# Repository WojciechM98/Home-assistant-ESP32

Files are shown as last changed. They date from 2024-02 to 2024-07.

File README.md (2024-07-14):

# Home-assistant-ESP32
Home assistand board using ESP32 controlled with MQTT protocol.

## Main purpose of Home assistant board
The project was created with the thought of controlling LED strips with MQTT protocol via phone app. A moment later, the idea of controlling and connecting many devices appeared such as water pump for watering plants plants, temperature sensors, lamps and so on.
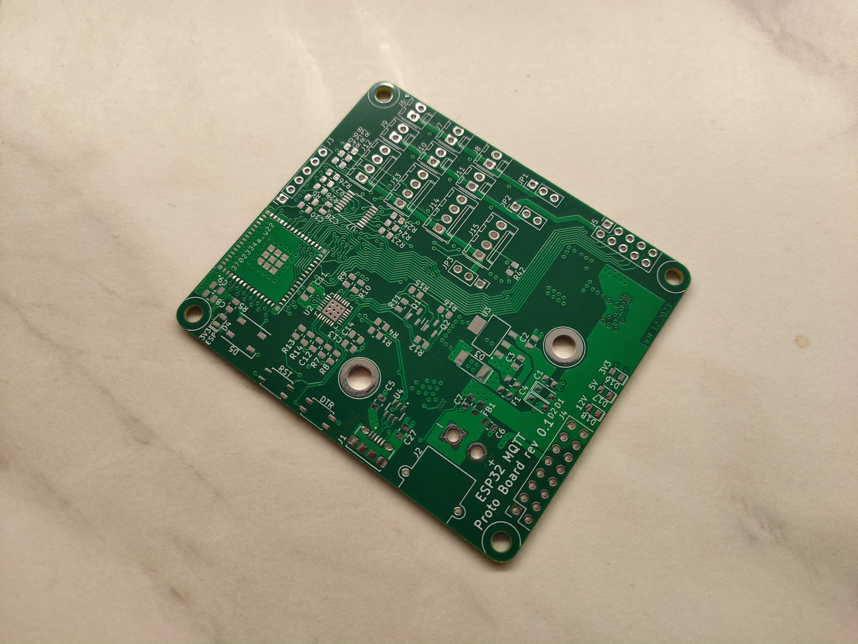
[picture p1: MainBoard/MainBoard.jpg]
Main board prototype version 0.2.


Prototype mainboard version 0.1 consist of:
- Espressif ESP32 S2 mini 1 chip,
- CP2102N series USB to UART bridge controller,
- XT30PW-M connector for powering board with up to 15V DC external power source,
- Onboard 3.3V and 5V buck converters capable of 3A current load each,
- 4 I/O molex KK254 4 pin connectors,
- 8 output molex KK254 2 pin connectors,
- 2 connectors for additional expansion of the mainboard,
- UART pin header for externel programmer connection.

### I/O connectors
Each connector consists of ground and voltage pins (jumper selection 3.3V or 5V), output signal and input signal with ESD protection schottky diodes.

### Output connectors
Output connector consists of voltage pin (jumper selection 3.3V, 5V or external power from XT30PW-M connector) and n-mosfet switching to ground. Those headers are capable of PWM control. Used DMN3023L mosfets are capable of 30V and up to 6.3A continous drain current. There is also super fast recovery DFLU1200-7 diode protecting device from reverse current flow.

### Additional expansion connectors
Those connectors uses the rest of gpio ESP pins and also provide SPI and I2C protocols.

## ACControl board
This board allows to control AC powered devices.
Control signals are seperated from AC side with SFH6156-1T optotransistors for safety purpose. AZ921-1A-12DE relays are used for switching AC current.
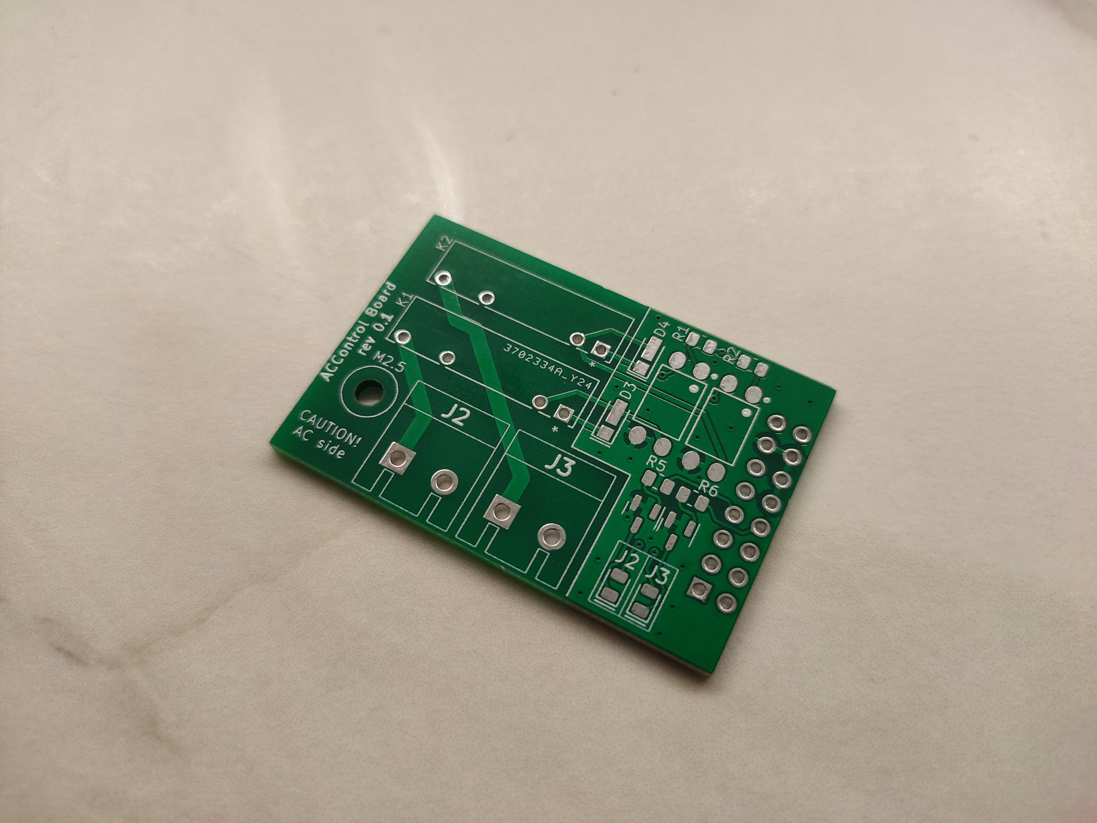
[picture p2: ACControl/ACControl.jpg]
ACControl prototype version 0.1.


## TempSensRTC
Addidtional board for temperature measurement. Can be used with MAX31865 chip for resisatance temperature detectors (RTDs) or with MAX31855 chip that allows to use theremocouples like K-type thermocouple. 
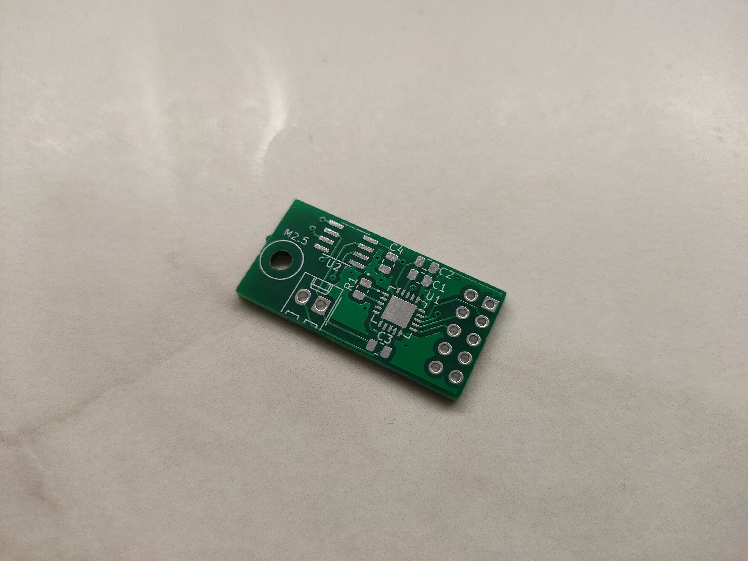
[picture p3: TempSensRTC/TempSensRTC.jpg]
TempSensRTC prototype version 0.1.


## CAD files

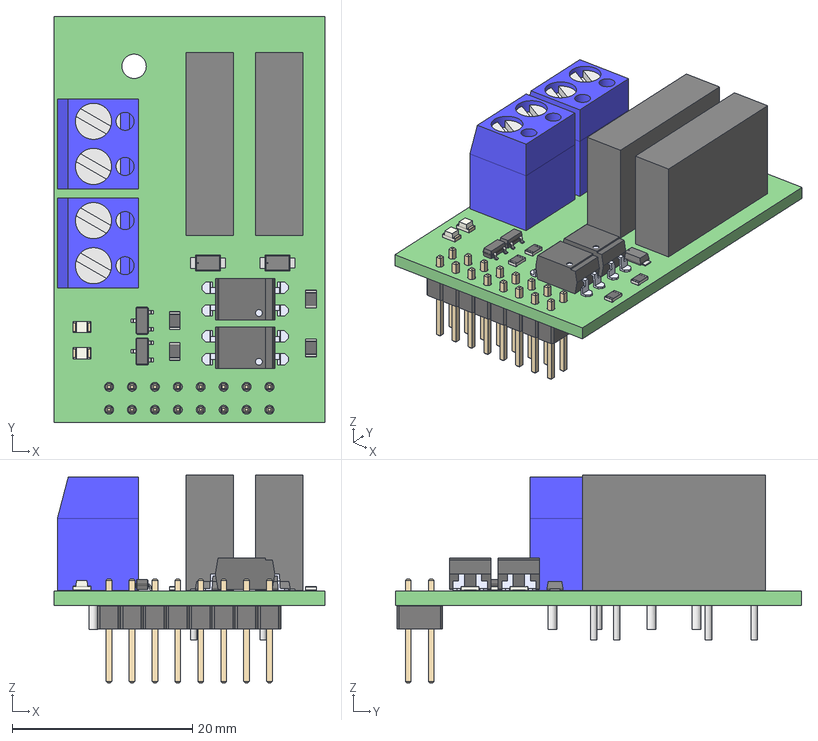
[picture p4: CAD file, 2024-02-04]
ACControl/control.step
30.0 x 45.0 x 23.0 mm
ACControl PCB

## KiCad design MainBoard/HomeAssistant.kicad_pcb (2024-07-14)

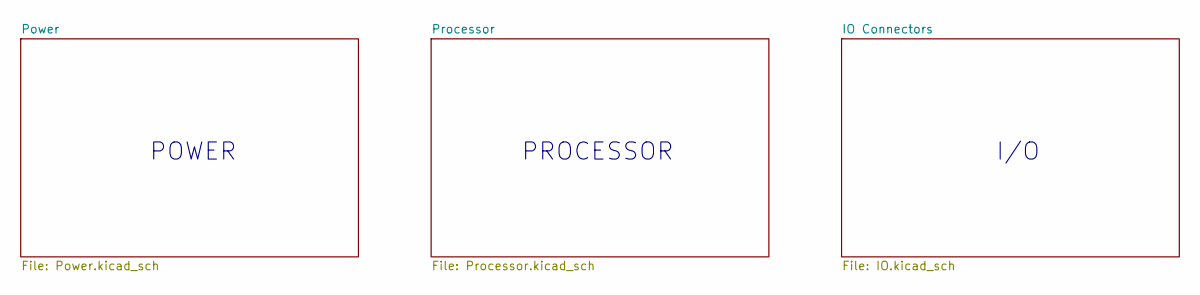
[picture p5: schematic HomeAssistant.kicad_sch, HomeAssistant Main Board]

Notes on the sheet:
I/O
POWER
PROCESSOR

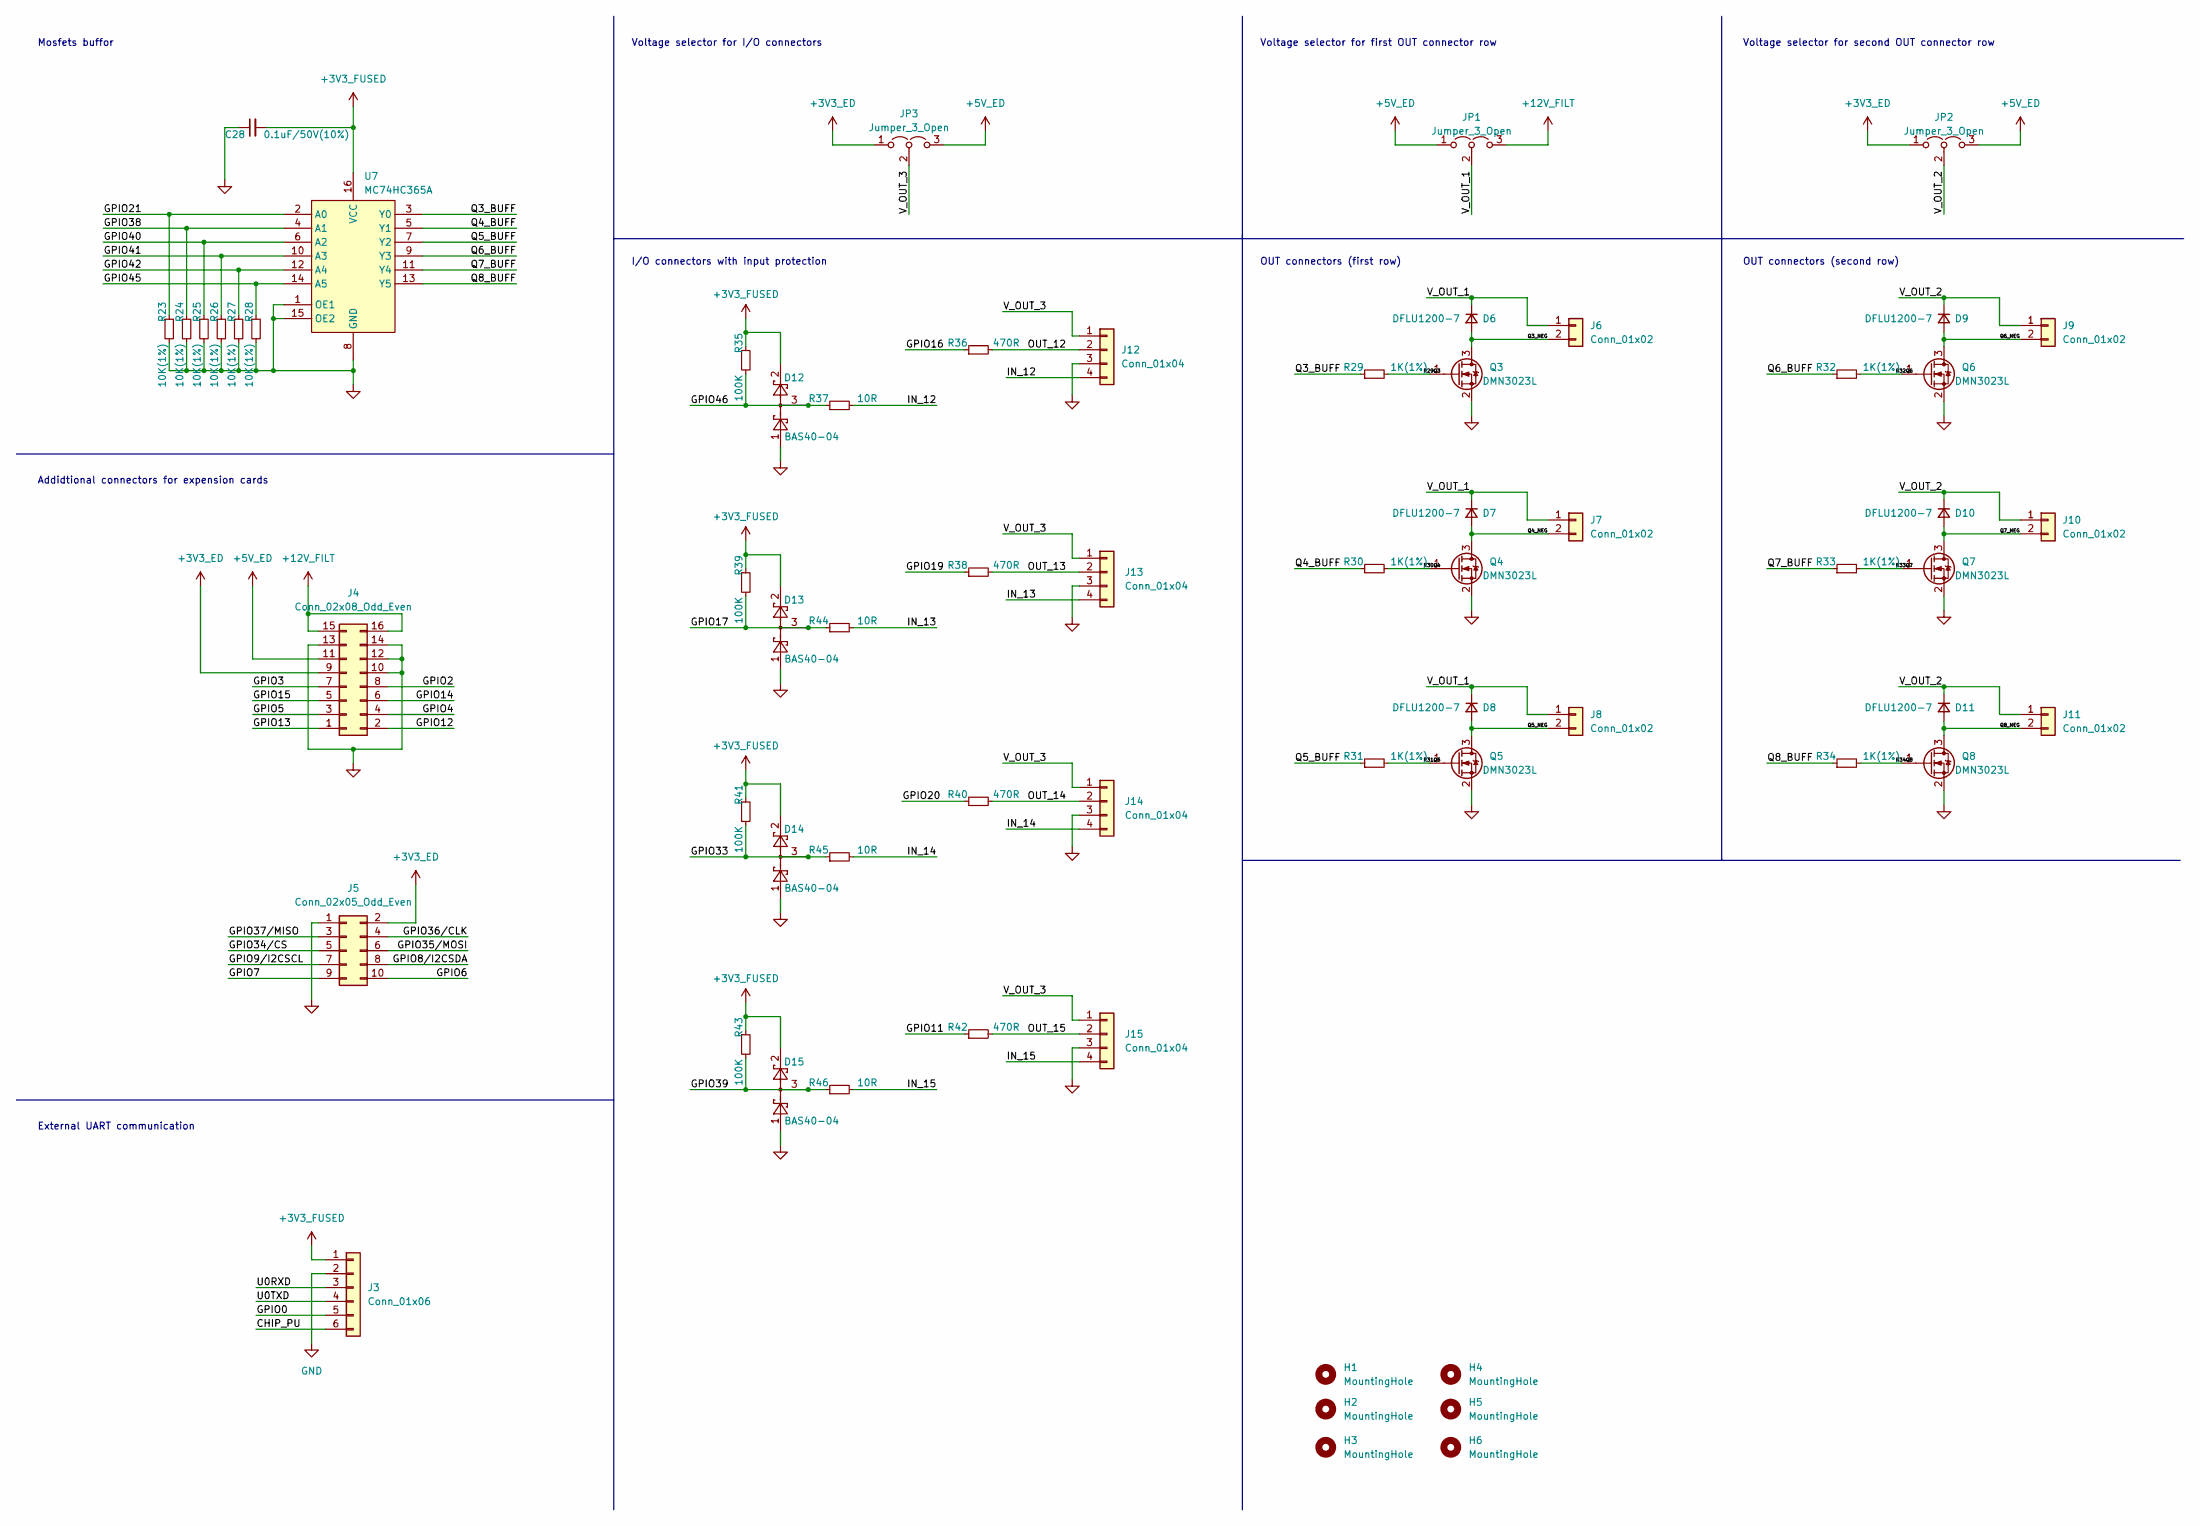
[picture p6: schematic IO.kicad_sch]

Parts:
C28: 0.1uF/50V(10%); C_0805_2012Metric
D6, D7, D8, D9, D10, D11: DFLU1200-7; DIODE_DFLU1200_1P93X3_DIO
D12, D13, D14, D15: BAS40-04; SOT-23
H1, H2, H3, H4: MountingHole; MountingHole_3.2mm_M3
H5, H6: MountingHole; SMTSO-M25-2ET
J3: Conn_01x06; PinSocket_1x06_P2.54mm_Vertical
J4: Conn_02x08_Odd_Even; PinSocket_2x08_P2.54mm_Vertical
J5: Conn_02x05_Odd_Even; PinSocket_2x05_P2.54mm_Vertical
J6, J7, J8, J9, J10, J11: Conn_01x02; Molex_KK-254_AE-6410-02A_1x02_P2.54mm_Vertical
J12, J13, J14, J15: Conn_01x04; Molex_KK-254_AE-6410-04A_1x04_P2.54mm_Vertical
JP1, JP2, JP3: Jumper_3_Open; PinHeader_1x03_P2.54mm_Vertical
Q3, Q4, Q5, Q6, Q7, Q8: DMN3023L; SOT-23
R23, R24, R25, R26, R27, R28: 10K(1%); R_0805_2012Metric
R29, R30, R31, R32, R33, R34: 1K(1%); R_0805_2012Metric
R35, R39, R41, R43: 100K; R_0805_2012Metric
R36, R38, R40, R42: 470R; R_0805_2012Metric
R37, R44, R45, R46: 10R; R_0805_2012Metric
U7: MC74HC365A; TSSOP-16_4.4x5mm_P0.65mm

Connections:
+3V3_ED: J4.9, J5.2, JP2.1 (A), JP3.1 (A); also elsewhere on the board
+3V3_FUSED: C28.2, D12.2, D13.2, D14.2, D15.2, J3.1, R35.1, R39.1, R41.1, R43.1, U7.16 (VCC); also elsewhere on the board
+5V_ED: J4.11, JP1.1 (A), JP2.3 (B), JP3.3 (B); also elsewhere on the board
+12V_FILT: J4.15, J4.16, JP1.3 (B); also elsewhere on the board
/IO Connectors/CHIP_PU: J3.6
/IO Connectors/GPIO0: J3.5
/IO Connectors/GPIO2: J4.8
/IO Connectors/GPIO3: J4.7
/IO Connectors/GPIO4: J4.4
/IO Connectors/GPIO5: J4.3
/IO Connectors/GPIO6: J5.10
/IO Connectors/GPIO7: J5.9
/IO Connectors/GPIO8/I2CSDA: J5.8
/IO Connectors/GPIO9/I2CSCL: J5.7
/IO Connectors/GPIO11: R42.1
/IO Connectors/GPIO12: J4.2
/IO Connectors/GPIO13: J4.1
/IO Connectors/GPIO14: J4.6
/IO Connectors/GPIO15: J4.5
/IO Connectors/GPIO17: D13.3, R39.2, R44.1
/IO Connectors/GPIO21: R23.1, U7.2 (A0)
/IO Connectors/GPIO33: D14.3, R41.2, R45.1
/IO Connectors/GPIO34/CS: J5.5
/IO Connectors/GPIO35/MOSI: J5.6
/IO Connectors/GPIO36/CLK: J5.4
/IO Connectors/GPIO37/MISO: J5.3
/IO Connectors/GPIO38: R24.1, U7.4 (A1)
/IO Connectors/GPIO39: D15.3, R43.2, R46.1
/IO Connectors/GPIO40: R25.1, U7.6 (A2)
/IO Connectors/GPIO41: R26.1, U7.10 (A3)
/IO Connectors/GPIO42: R27.1, U7.12 (A4)
/IO Connectors/GPIO45: R28.1, U7.14 (A5)
/IO Connectors/GPIO46: D12.3, R35.2, R37.1
/IO Connectors/IN_12: J12.4, R37.2
/IO Connectors/IN_13: J13.4, R44.2
/IO Connectors/IN_14: J14.4, R45.2
/IO Connectors/IN_15: J15.4, R46.2
/IO Connectors/OUT_12: J12.2, R36.2
/IO Connectors/OUT_13: J13.2, R38.2
/IO Connectors/OUT_14: J14.2, R40.2
/IO Connectors/OUT_15: J15.2, R42.2
/IO Connectors/Q3_BUFF: R29.1, U7.3 (Y0)
/IO Connectors/Q3_NEG: D6.2 (A), J6.2, Q3.3 (D)
/IO Connectors/Q4_BUFF: R30.1, U7.5 (Y1)
/IO Connectors/Q4_NEG: D7.2 (A), J7.2, Q4.3 (D)
/IO Connectors/Q5_BUFF: R31.1, U7.7 (Y2)
/IO Connectors/Q5_NEG: D8.2 (A), J8.2, Q5.3 (D)
/IO Connectors/Q6_BUFF: R32.1, U7.9 (Y3)
/IO Connectors/Q6_NEG: D9.2 (A), J9.2, Q6.3 (D)
/IO Connectors/Q7_BUFF: R33.1, U7.11 (Y4)
/IO Connectors/Q7_NEG: D10.2 (A), J10.2, Q7.3 (D)
/IO Connectors/Q8_BUFF: R34.1, U7.13 (Y5)
/IO Connectors/Q8_NEG: D11.2 (A), J11.2, Q8.3 (D)
/IO Connectors/R29Q3: Q3.1 (G), R29.2
/IO Connectors/R30Q4: Q4.1 (G), R30.2
/IO Connectors/R31Q5: Q5.1 (G), R31.2
/IO Connectors/R32Q6: Q6.1 (G), R32.2
/IO Connectors/R33Q7: Q7.1 (G), R33.2
/IO Connectors/R34Q8: Q8.1 (G), R34.2
/IO Connectors/U0RXD: J3.3
/IO Connectors/U0TXD: J3.4
/IO Connectors/V_OUT_1: D6.1 (K), D7.1 (K), D8.1 (K), J6.1, J7.1, J8.1, JP1.2 (C)
/IO Connectors/V_OUT_2: D9.1 (K), D10.1 (K), D11.1 (K), J9.1, J10.1, J11.1, JP2.2 (C)
/IO Connectors/V_OUT_3: J12.1, J13.1, J14.1, J15.1, JP3.2 (C)
/Processor/GPIO16: R36.1; also elsewhere on the board
/Processor/GPIO19: R38.1; also elsewhere on the board
/Processor/GPIO20: R40.1; also elsewhere on the board
GND: C28.1, D12.1, D13.1, D14.1, D15.1, J3.2, J4.10, J4.12, J4.13, J4.14, J5.1, J12.3, J13.3, J14.3, J15.3, Q3.2 (S), Q4.2 (S), Q5.2 (S), Q6.2 (S), Q7.2 (S), Q8.2 (S), R23.2, R24.2, R25.2, R26.2, R27.2, R28.2, U7.1 (OE1), U7.8 (GND), U7.15 (OE2); also elsewhere on the board

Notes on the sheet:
OUT connectors (second row)
Voltage selector for second OUT connector row
Mosfets buffor
I/O connectors with input protection
External UART communication
Voltage selector for I/O connectors
OUT connectors (first row)
Voltage selector for first OUT connector row
Addidtional connectors for expension cards

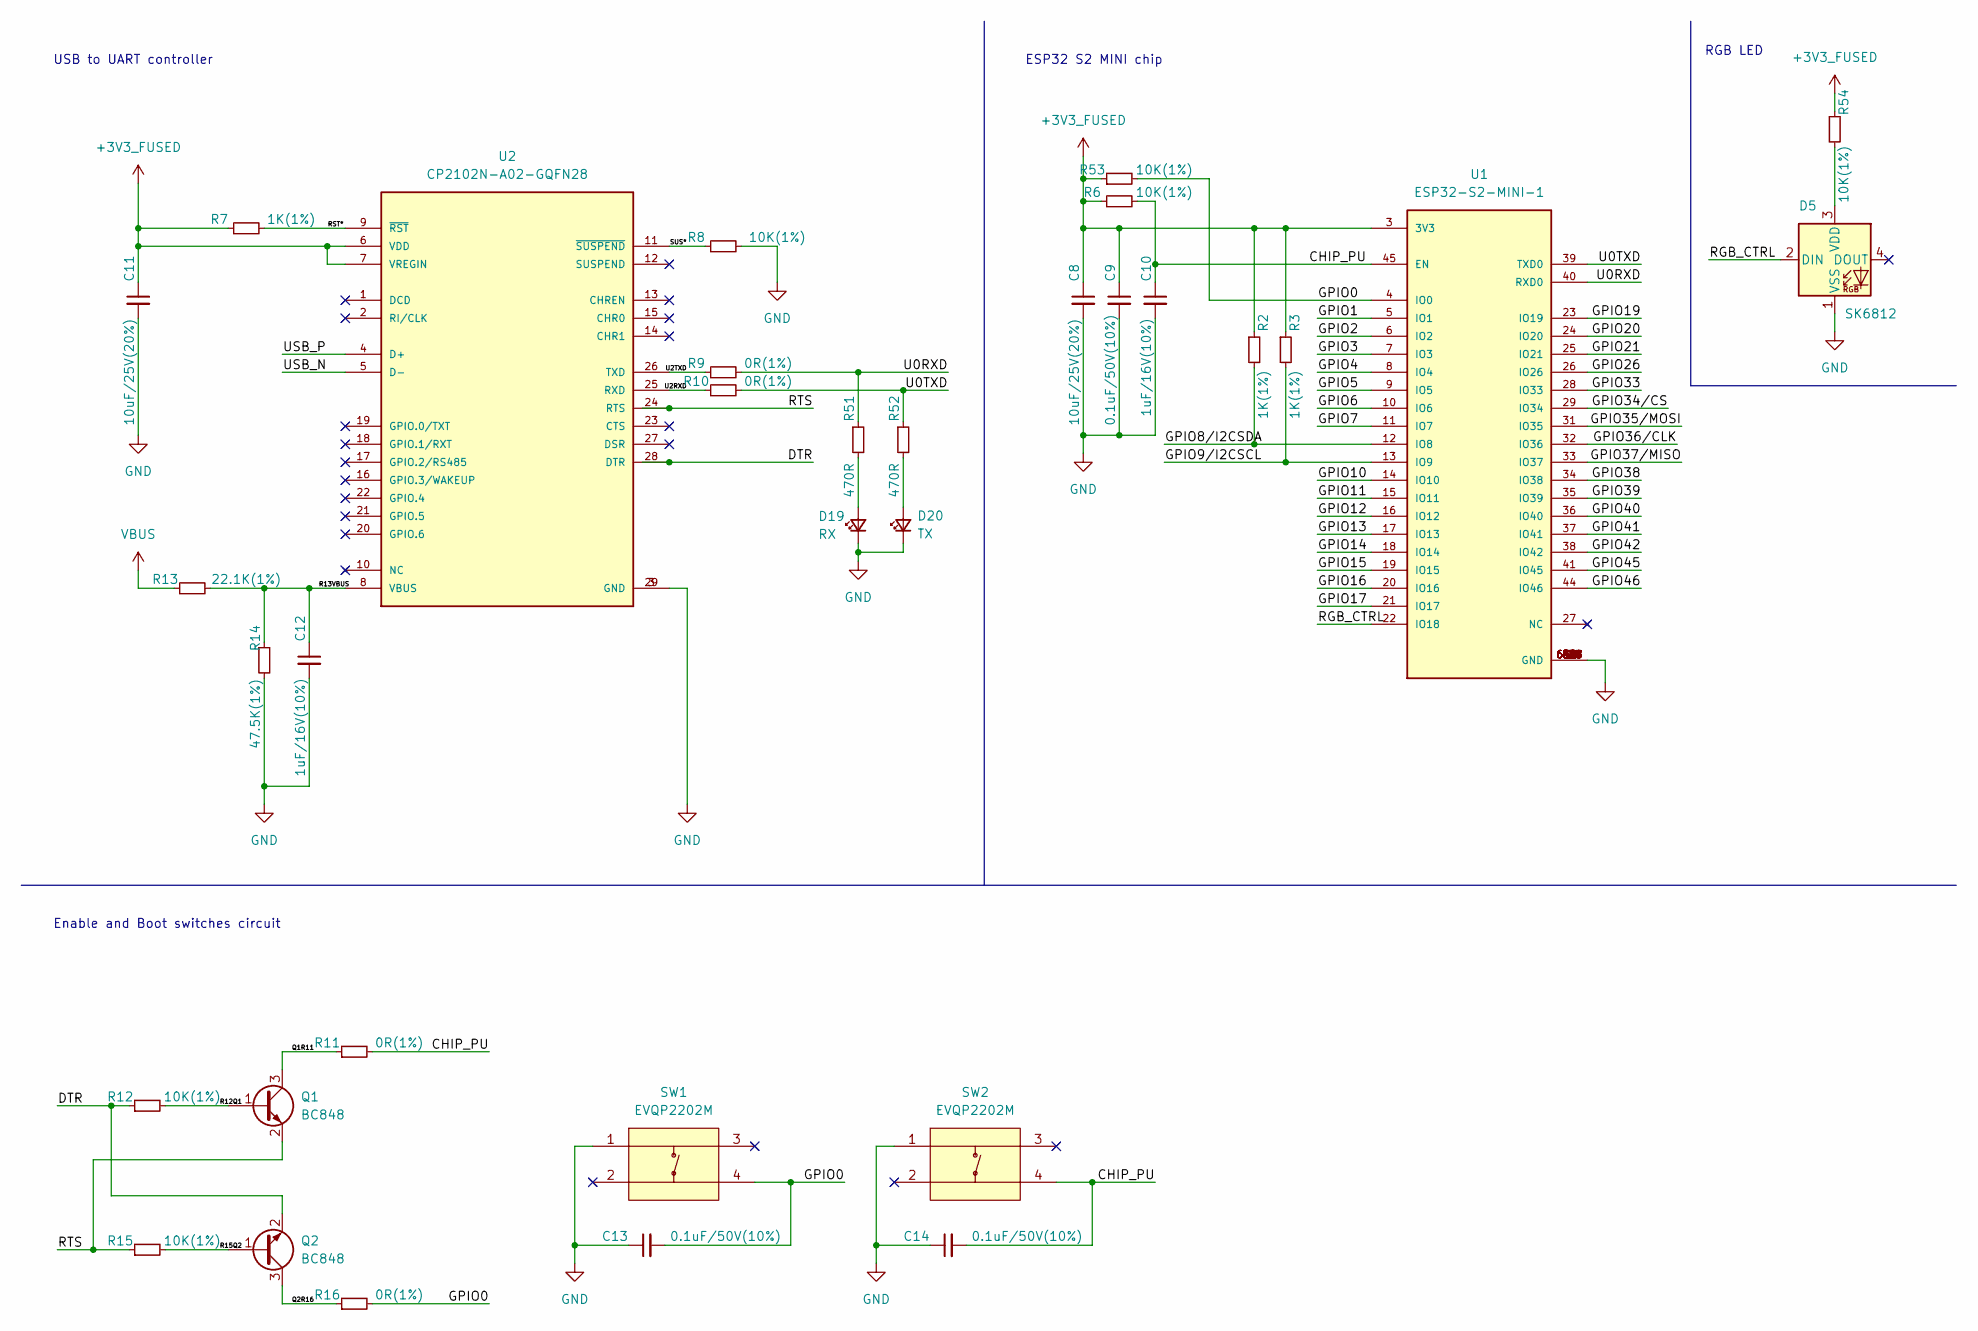
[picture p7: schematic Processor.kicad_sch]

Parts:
C8, C11: 10uF/25V(20%); C_0805_2012Metric
C9, C13, C14: 0.1uF/50V(10%); C_0805_2012Metric
C10, C12: 1uF/16V(10%); C_0805_2012Metric
D5: SK6812; LED_SK6812_PLCC4_5.0x5.0mm_P3.2mm
D19: RX; LED_0805_2012Metric
D20: TX; LED_0805_2012Metric
Q1, Q2: BC848; SOT-23
R2, R3, R7: 1K(1%); R_0805_2012Metric
R6, R8, R12, R15, R53, R54: 10K(1%); R_0805_2012Metric
R9, R10, R11, R16: 0R(1%); R_0805_2012Metric
R13: 22.1K(1%); R_0805_2012Metric
R14: 47.5K(1%); R_0805_2012Metric
R51, R52: 470R; R_0805_2012Metric
SW1, SW2: EVQP2202M; TACT_EVQP2202M
U1: ESP32-S2-MINI-1; XCVR_ESP32-S2-MINI-1; PARTREV 1.0
U2: CP2102N-A02-GQFN28; QFN50P500X500X80-29N; PARTREV 1.5

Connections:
+3V3_FUSED: C8.1, C9.1, C11.1, R2.1, R3.1, R6.1, R7.1, R53.1, R54.1, U1.3 (3V3), U2.6 (VDD), U2.7 (VREGIN); also elsewhere on the board
/Processor/CHIP_PU: C10.1, C14.2, R6.2, R11.2, SW2.4, U1.45 (EN)
/Processor/DTR: Q2.2 (E), R12.1, U2.28 (DTR)
/Processor/GPIO0: C13.2, R16.2, R53.2, SW1.4, U1.4 (IO0)
/Processor/GPIO1: U1.5 (IO1)
/Processor/GPIO2: U1.6 (IO2)
/Processor/GPIO3: U1.7 (IO3)
/Processor/GPIO4: U1.8 (IO4)
/Processor/GPIO5: U1.9 (IO5)
/Processor/GPIO6: U1.10 (IO6)
/Processor/GPIO7: U1.11 (IO7)
/Processor/GPIO8/I2CSDA: R2.2, U1.12 (IO8)
/Processor/GPIO9/I2CSCL: R3.2, U1.13 (IO9)
/Processor/GPIO10: U1.14 (IO10)
/Processor/GPIO11: U1.15 (IO11)
/Processor/GPIO12: U1.16 (IO12)
/Processor/GPIO13: U1.17 (IO13)
/Processor/GPIO14: U1.18 (IO14)
/Processor/GPIO15: U1.19 (IO15)
/Processor/GPIO16: U1.20 (IO16); also elsewhere on the board
/Processor/GPIO17: U1.21 (IO17)
/Processor/GPIO19: U1.23 (IO19); also elsewhere on the board
/Processor/GPIO20: U1.24 (IO20); also elsewhere on the board
/Processor/GPIO21: U1.25 (IO21)
/Processor/GPIO26: U1.26 (IO26)
/Processor/GPIO33: U1.28 (IO33)
/Processor/GPIO34/CS: U1.29 (IO34)
/Processor/GPIO35/MOSI: U1.31 (IO35)
/Processor/GPIO36/CLK: U1.32 (IO36)
/Processor/GPIO37/MISO: U1.33 (IO37)
/Processor/GPIO38: U1.34 (IO38)
/Processor/GPIO39: U1.35 (IO39)
/Processor/GPIO40: U1.36 (IO40)
/Processor/GPIO41: U1.37 (IO41)
/Processor/GPIO42: U1.38 (IO42)
/Processor/GPIO45: U1.41 (IO45)
/Processor/GPIO46: U1.44 (IO46)
/Processor/Q1R11: Q1.3 (C), R11.1
/Processor/Q2R16: Q2.3 (C), R16.1
/Processor/R12Q1: Q1.1 (B), R12.2
/Processor/R13VBUS: C12.1, R13.2, R14.1, U2.8 (VBUS)
/Processor/R15Q2: Q2.1 (B), R15.2
/Processor/RGB_CTRL: D5.2 (DIN), U1.22 (IO18)
/Processor/RST*: R7.2, U2.9 (~RST)
/Processor/RTS: Q1.2 (E), R15.1, U2.24 (RTS)
/Processor/SUS*: R8.1, U2.11 (~SUSPEND)
/Processor/U0RXD: R9.2, R51.1, U1.40 (RXD0)
/Processor/U0TXD: R10.2, R52.1, U1.39 (TXD0)
/Processor/U2RXD: R10.1, U2.25 (RXD)
/Processor/U2TXD: R9.1, U2.26 (TXD)
/Processor/USB_N: U2.5 (D-)
/Processor/USB_P: U2.4 (D+)
GND: C8.2, C9.2, C10.2, C11.2, C12.2, C13.1, C14.1, D5.1 (VSS), D19.1 (K), D20.1 (K), R8.2, R14.2, SW1.1, SW2.1, U1.1 (GND), U1.2 (GND), U1.30 (GND), U1.42 (GND), U1.43 (GND), U1.46 (GND), U1.47 (GND), U1.48 (GND), U1.49 (GND), U1.50 (GND), U1.51 (GND), U1.52 (GND), U1.53 (GND), U1.54 (GND), U1.55 (GND), U1.56 (GND), U1.57 (GND), U1.58 (GND), U1.59 (GND), U1.60 (GND), U1.61 (GND), U1.61_1 (GND), U1.61_2 (GND), U1.61_3 (GND), U1.61_4 (GND), U1.61_5 (GND), U1.61_6 (GND), U1.61_7 (GND), U1.61_8 (GND), U1.62 (GND), U1.63 (GND), U1.64 (GND), U1.65 (GND), U2.3 (GND), U2.29 (GND); also elsewhere on the board
unnamed: D5.3 (VDD), R54.2
unnamed: D19.2 (A), R51.2
unnamed: D20.2 (A), R52.2
VBUS: R13.1; also elsewhere on the board

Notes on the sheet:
Enable and Boot switches circuit
RGB LED
USB to UART controller
ESP32 S2 MINI chip

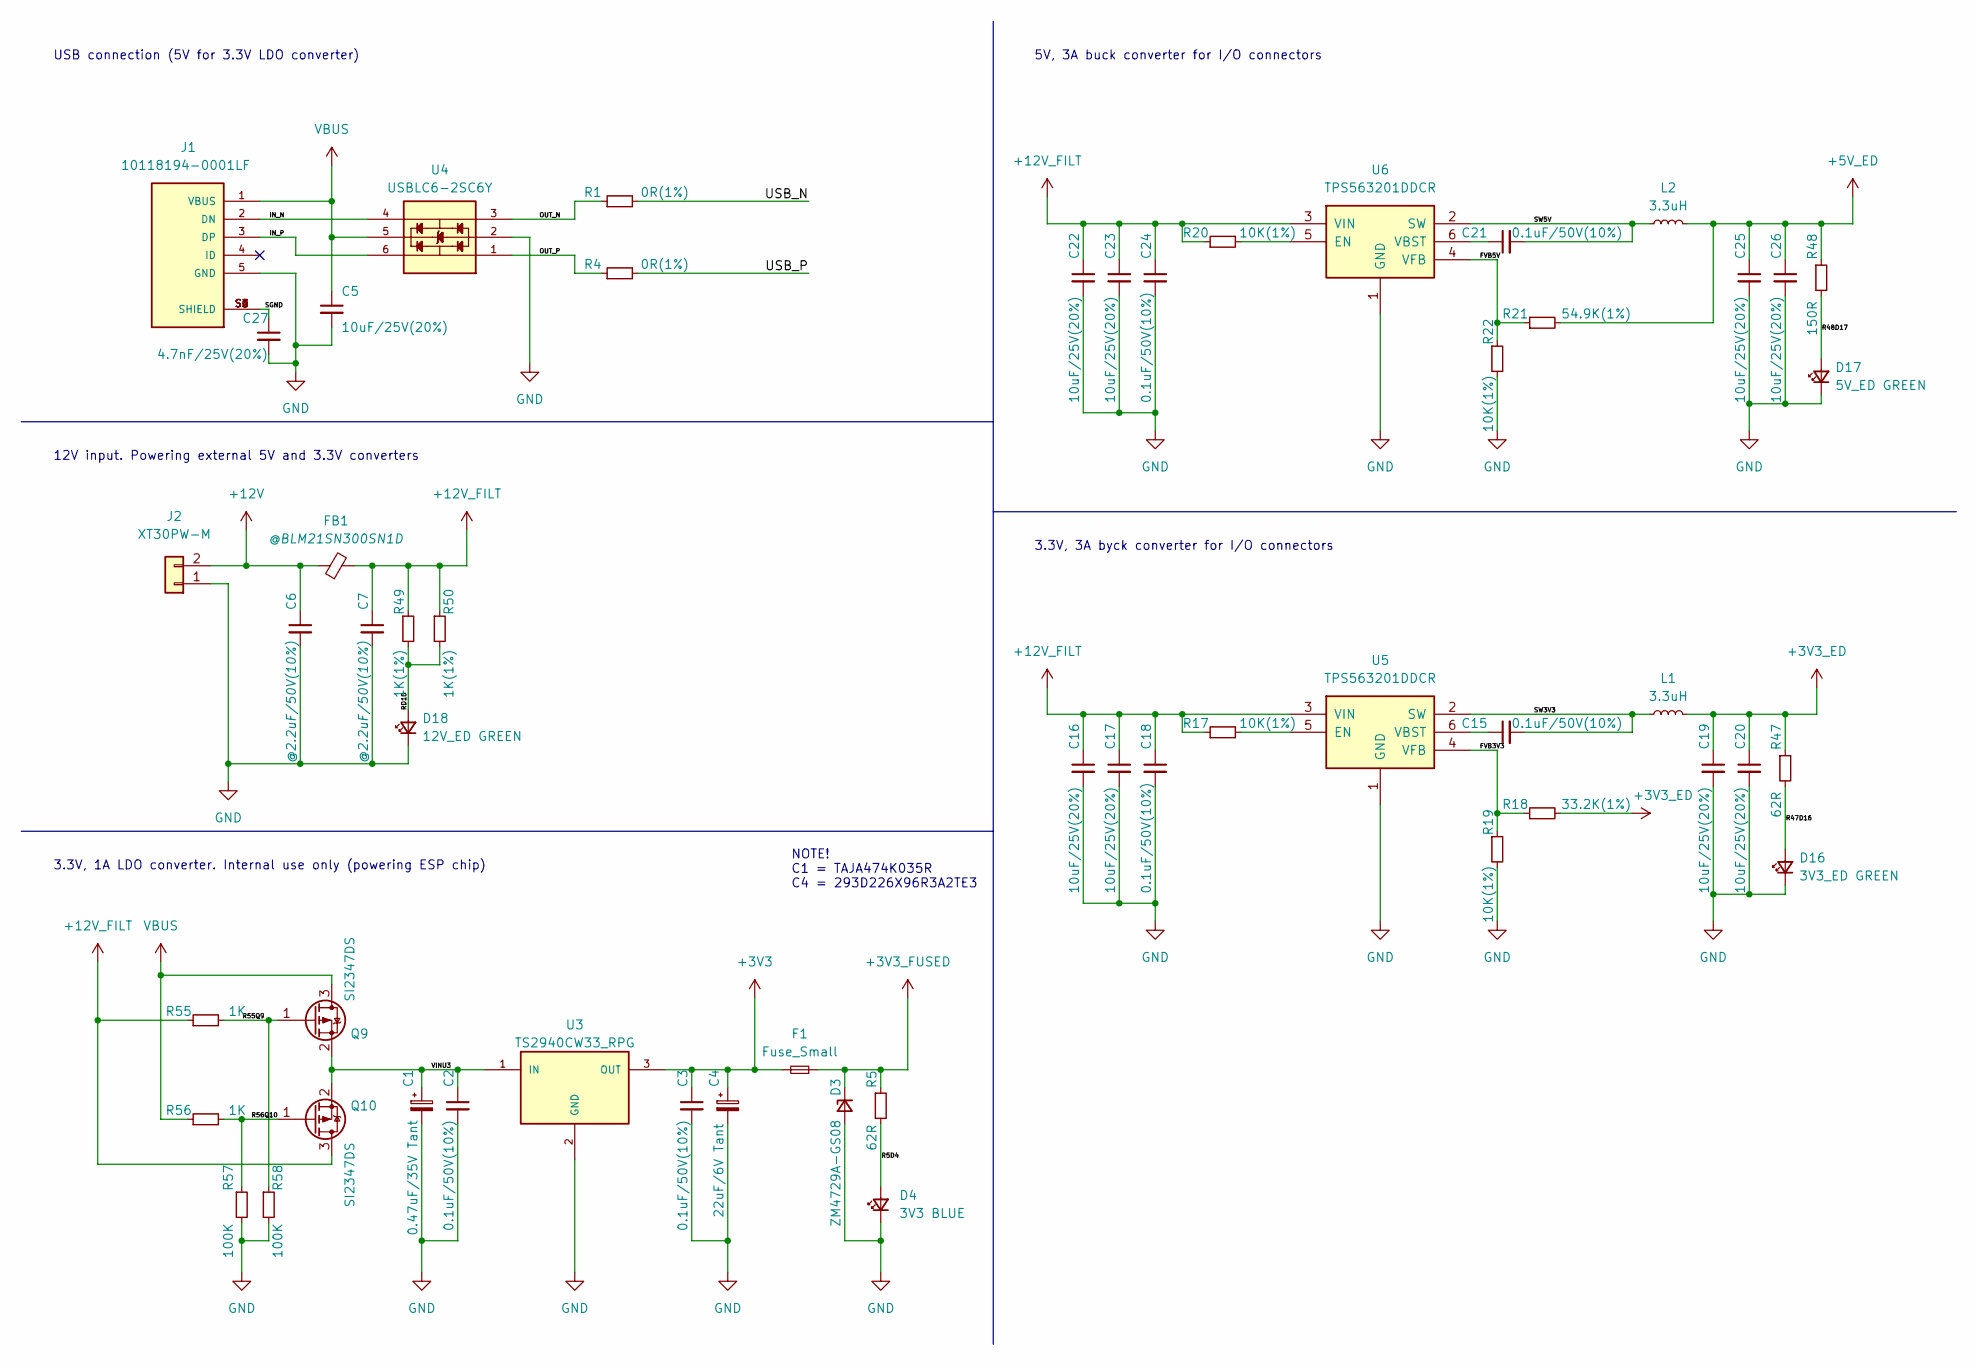
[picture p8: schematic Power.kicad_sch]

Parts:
C1: 0.47uF/35V Tant; CP_EIA-3216-18_Kemet-A
C2, C3, C15, C18, C21, C24: 0.1uF/50V(10%); C_0805_2012Metric
C4: 22uF/6V Tant; CP_EIA-3216-18_Kemet-A
C5, C16, C17, C19, C20, C22, C23, C25, C26: 10uF/25V(20%); C_0805_2012Metric
C6, C7: @2.2uF/50V(10%); C_0805_2012Metric
C27: 4.7nF/25V(20%); C_0805_2012Metric
D3: ZM4729A-GS08; D_MELF
D4: 3V3 BLUE; LED_0805_2012Metric
D16: 3V3_ED GREEN; LED_0805_2012Metric
D17: 5V_ED GREEN; LED_0805_2012Metric
D18: 12V_ED GREEN; LED_0805_2012Metric
F1: Fuse_Small; Fuse_0805_2012Metric
FB1: @BLM21SN300SN1D; Fuse_0805_2012Metric
J1: 10118194-0001LF; USB_AMPHENOL_10118194-0001LF; PARTREV D
J2: XT30PW-M; AMASS_XT30PW-M_1x02_P2.50mm_Horizontal
L1, L2: 3.3uH; INDM7676X355N
Q9, Q10: SI2347DS; TSOT-23
R1, R4: 0R(1%); R_0805_2012Metric
R5, R47: 62R; R_0805_2012Metric
R17, R19, R20, R22: 10K(1%); R_0805_2012Metric
R18: 33.2K(1%); R_0805_2012Metric
R21: 54.9K(1%); R_0805_2012Metric
R48: 150R; R_0805_2012Metric
R49, R50: 1K(1%); R_0805_2012Metric
R55, R56: 1K; R_0805_2012Metric
R57, R58: 100K; R_0805_2012Metric
U3: TS2940CW33_RPG; VREG_TS2940CW33_RPG; PARTREV E15
U4: USBLC6-2SC6Y; SOT95P280X145-6N
U5, U6: TPS563201DDCR; SOT95P280X110-6N; PARTREV December 2015

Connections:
+3V3: C3.1, C4.1, F1.2, U3.3 (OUT)
+3V3_ED: C19.1, C20.1, L1.2, R18.2, R47.1; also elsewhere on the board
+3V3_FUSED: D3.1 (K), F1.1, R5.1; also elsewhere on the board
+5V_ED: C25.1, C26.1, L2.2, R21.2, R48.1; also elsewhere on the board
+12V: C6.1, FB1.1, J2.2
+12V_FILT: C7.1, C16.1, C17.1, C18.1, C22.1, C23.1, C24.1, FB1.2, Q10.3 (D), R17.1, R20.1, R49.1, R50.1, R55.1, U5.3 (VIN), U6.3 (VIN); also elsewhere on the board
/Power/FVB3V3: R18.1, R19.1, U5.4 (VFB)
/Power/FVB5V: R21.1, R22.1, U6.4 (VFB)
/Power/IN_N: J1.2 (DN), U4.4
/Power/IN_P: J1.3 (DP), U4.6
/Power/OUT_N: R1.1, U4.3
/Power/OUT_P: R4.1, U4.1
/Power/R5D4: D4.2 (A), R5.2
/Power/R47D16: D16.2 (A), R47.2
/Power/R48D17: D17.2 (A), R48.2
/Power/R55Q9: Q9.1 (G), R55.2, R58.1
/Power/R56Q10: Q10.1 (G), R56.2, R57.1
/Power/RD18: D18.2 (A), R49.2, R50.2
/Power/SGND: C27.1, J1.S1 (SHIELD), J1.S2 (SHIELD), J1.S3 (SHIELD), J1.S4 (SHIELD), J1.S5 (SHIELD), J1.S6 (SHIELD)
/Power/SW3V3: C15.2, L1.1, U5.2 (SW)
/Power/SW5V: C21.2, L2.1, U6.2 (SW)
/Power/USB_N: R1.2
/Power/USB_P: R4.2
/Power/VINU3: C1.1, C2.1, Q9.2 (S), Q10.2 (S), U3.1 (IN)
GND: C1.2, C2.2, C3.2, C4.2, C5.2, C6.2, C7.2, C16.2, C17.2, C18.2, C19.2, C20.2, C22.2, C23.2, C24.2, C25.2, C26.2, C27.2, D3.2 (A), D4.1 (K), D16.1 (K), D17.1 (K), D18.1 (K), J1.5 (GND), J2.1, R19.2, R22.2, R57.2, R58.2, U3.2 (GND), U4.2, U5.1 (GND), U6.1 (GND); also elsewhere on the board
unnamed: C15.1, U5.6 (VBST)
unnamed: C21.1, U6.6 (VBST)
unnamed: R17.2, U5.5 (EN)
unnamed: R20.2, U6.5 (EN)
VBUS: C5.1, J1.1 (VBUS), Q9.3 (D), R56.1, U4.5; also elsewhere on the board

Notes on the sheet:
3.3V, 3A byck converter for I/O connectors
5V, 3A buck converter for I/O connectors
USB connection (5V for 3.3V LDO converter)
3.3V, 1A LDO converter. Internal use only (powering ESP chip)
NOTE! C1 = TAJA474K035R C4 = 293D226X96R3A2TE3
12V input. Powering external 5V and 3.3V converters

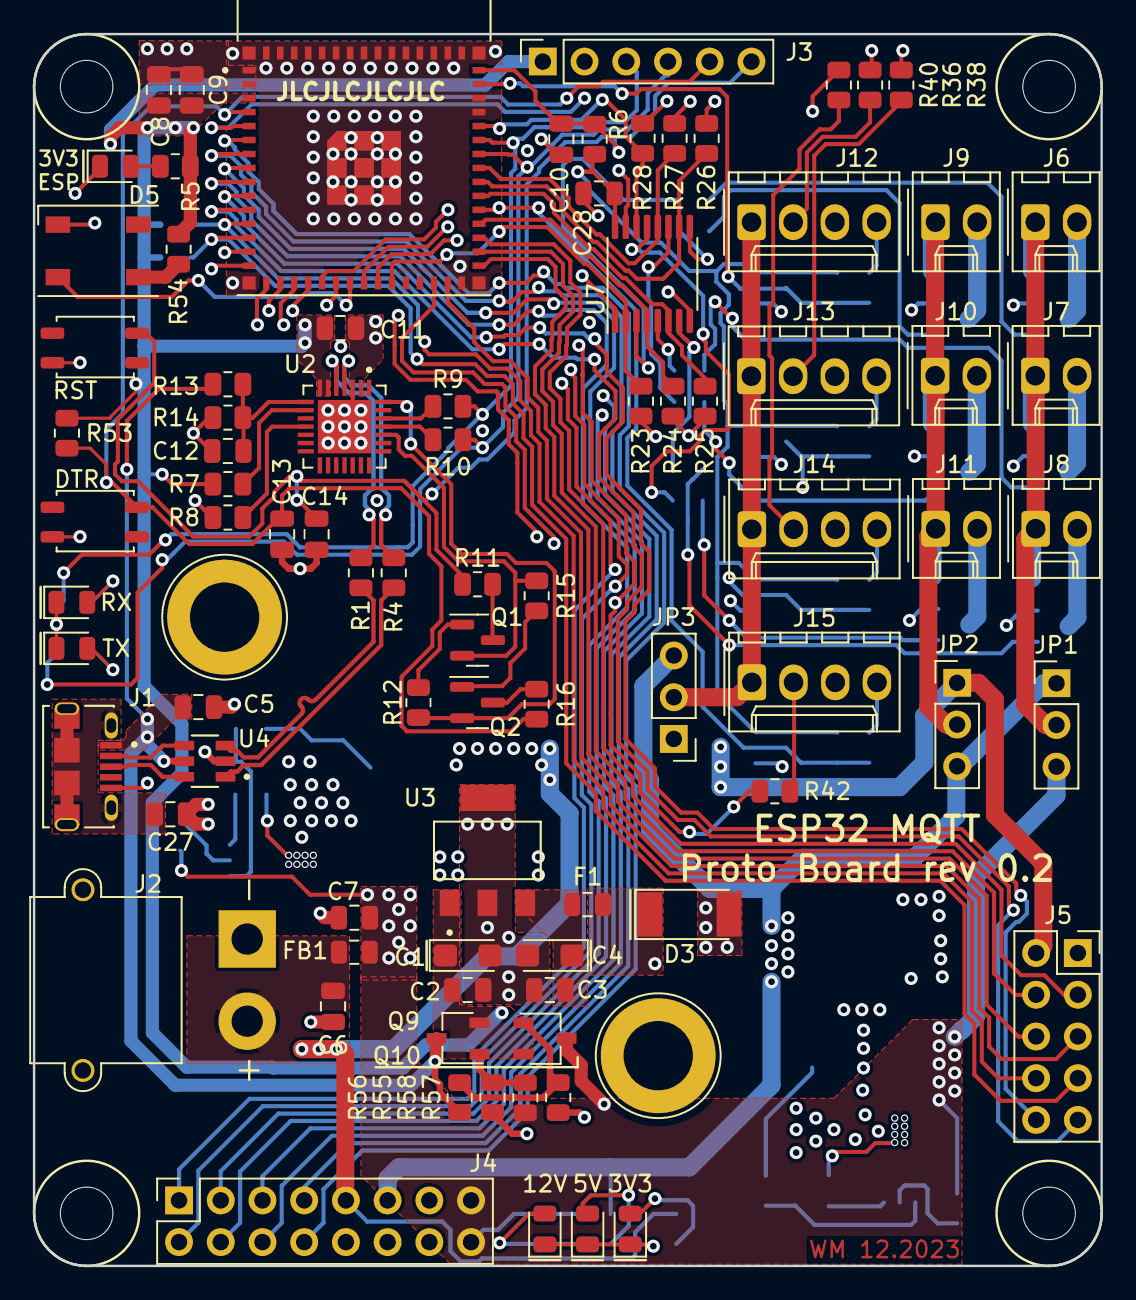
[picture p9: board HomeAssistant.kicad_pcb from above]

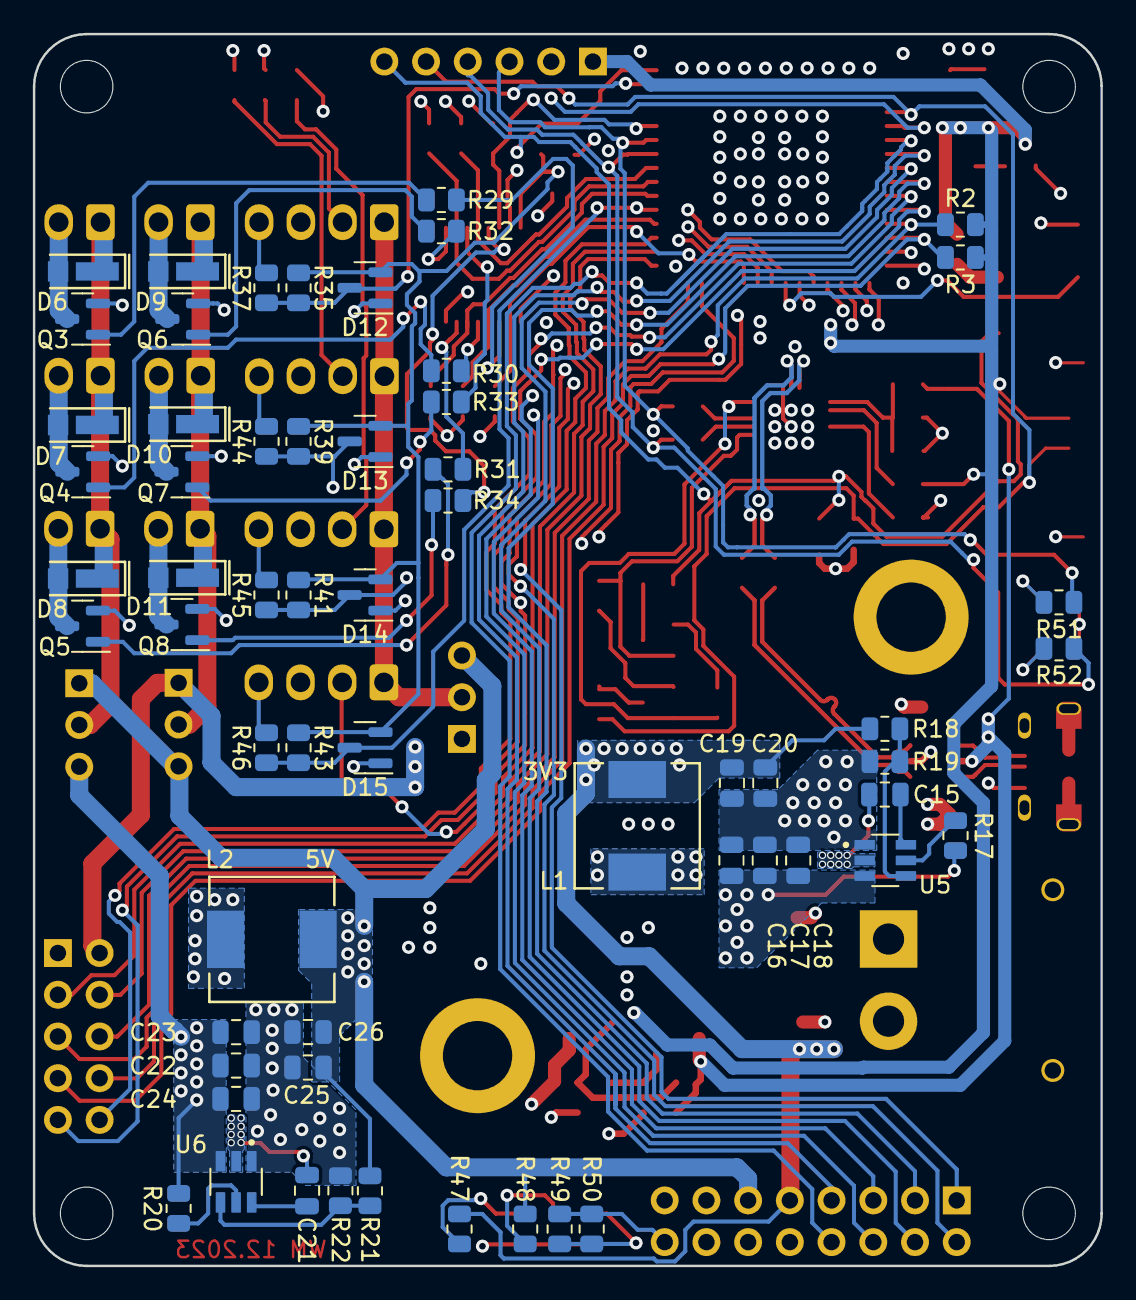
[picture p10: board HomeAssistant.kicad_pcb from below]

Board: 4 copper layers, 65.0 x 75.0 mm, 151 parts (60 on the bottom side), 91 nets.

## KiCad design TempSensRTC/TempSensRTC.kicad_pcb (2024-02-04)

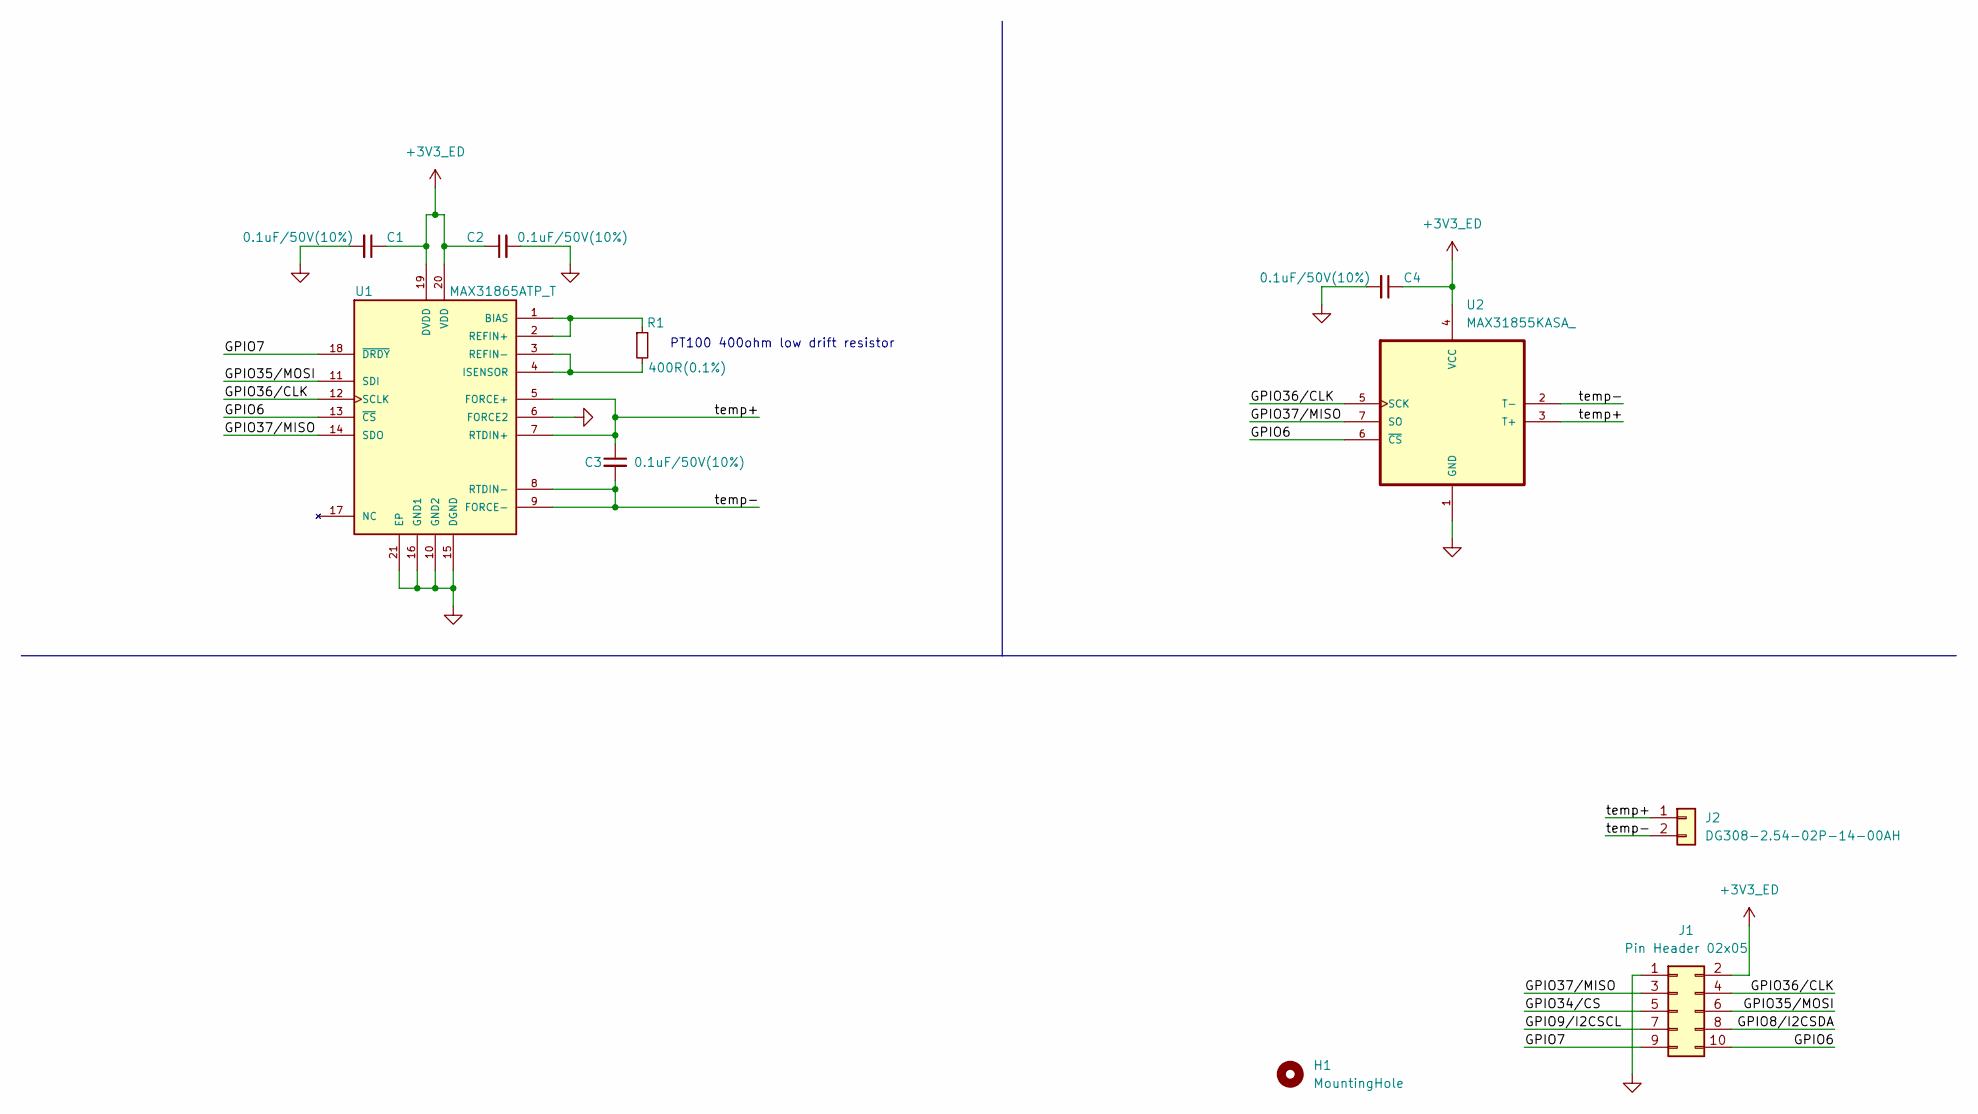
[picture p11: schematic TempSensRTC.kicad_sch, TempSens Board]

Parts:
C1, C2, C3, C4: 0.1uF/50V(10%); C_0805_2012Metric
H1: MountingHole; MountingHole_2.7mm_M2.5
J1: Pin Header 02x05; PinHeader_2x05_P2.54mm_Vertical
J2: DG308-2.54-02P-14-00AH; Molex_KK-254_AE-6410-02A_1x02_P2.54mm_Vertical
R1: 400R(0.1%); R_0805_2012Metric
U1: MAX31865ATP_T; QFN65P500X500X80-21N; PARTREV 3
U2: MAX31855KASA_; SOIC127P600X175-8N

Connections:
+3V3_ED: C1.1, C2.1, C4.1, J1.2, U1.19 (DVDD), U1.20 (VDD), U2.4 (VCC)
/GPIO6: J1.10, U1.13 (~CS), U2.6 (~CS)
/GPIO7: J1.9, U1.18 (~DRDY)
/GPIO8/I2CSDA: J1.8
/GPIO9/I2CSCL: J1.7
/GPIO34/CS: J1.5
/GPIO35/MOSI: J1.6, U1.11 (SDI)
/GPIO36/CLK: J1.4, U1.12 (SCLK), U2.5 (SCK)
/GPIO37/MISO: J1.3, U1.14 (SDO), U2.7 (SO)
/temp+: C3.1, J2.1, U1.5 (FORCE+), U1.7 (RTDIN+), U2.3 (T+)
/temp-: C3.2, J2.2, U1.8 (RTDIN-), U1.9 (FORCE-), U2.2 (T-)
GND: C1.2, C2.2, C4.2, J1.1, U1.6 (FORCE2), U1.10 (GND2), U1.15 (DGND), U1.16 (GND1), U1.21 (EP), U2.1 (GND)
unnamed: R1.1, U1.1 (BIAS), U1.2 (REFIN+)
unnamed: R1.2, U1.3 (REFIN-), U1.4 (ISENSOR)

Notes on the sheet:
PT100 400ohm low drift resistor

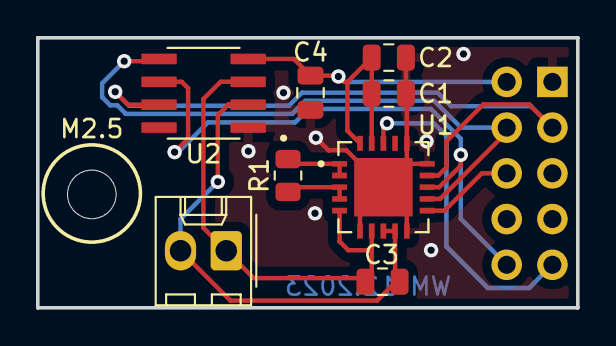
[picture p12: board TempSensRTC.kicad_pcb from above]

Board: 2 copper layers, 30.0 x 15.0 mm, 10 parts (1 on the bottom side), 11 nets.

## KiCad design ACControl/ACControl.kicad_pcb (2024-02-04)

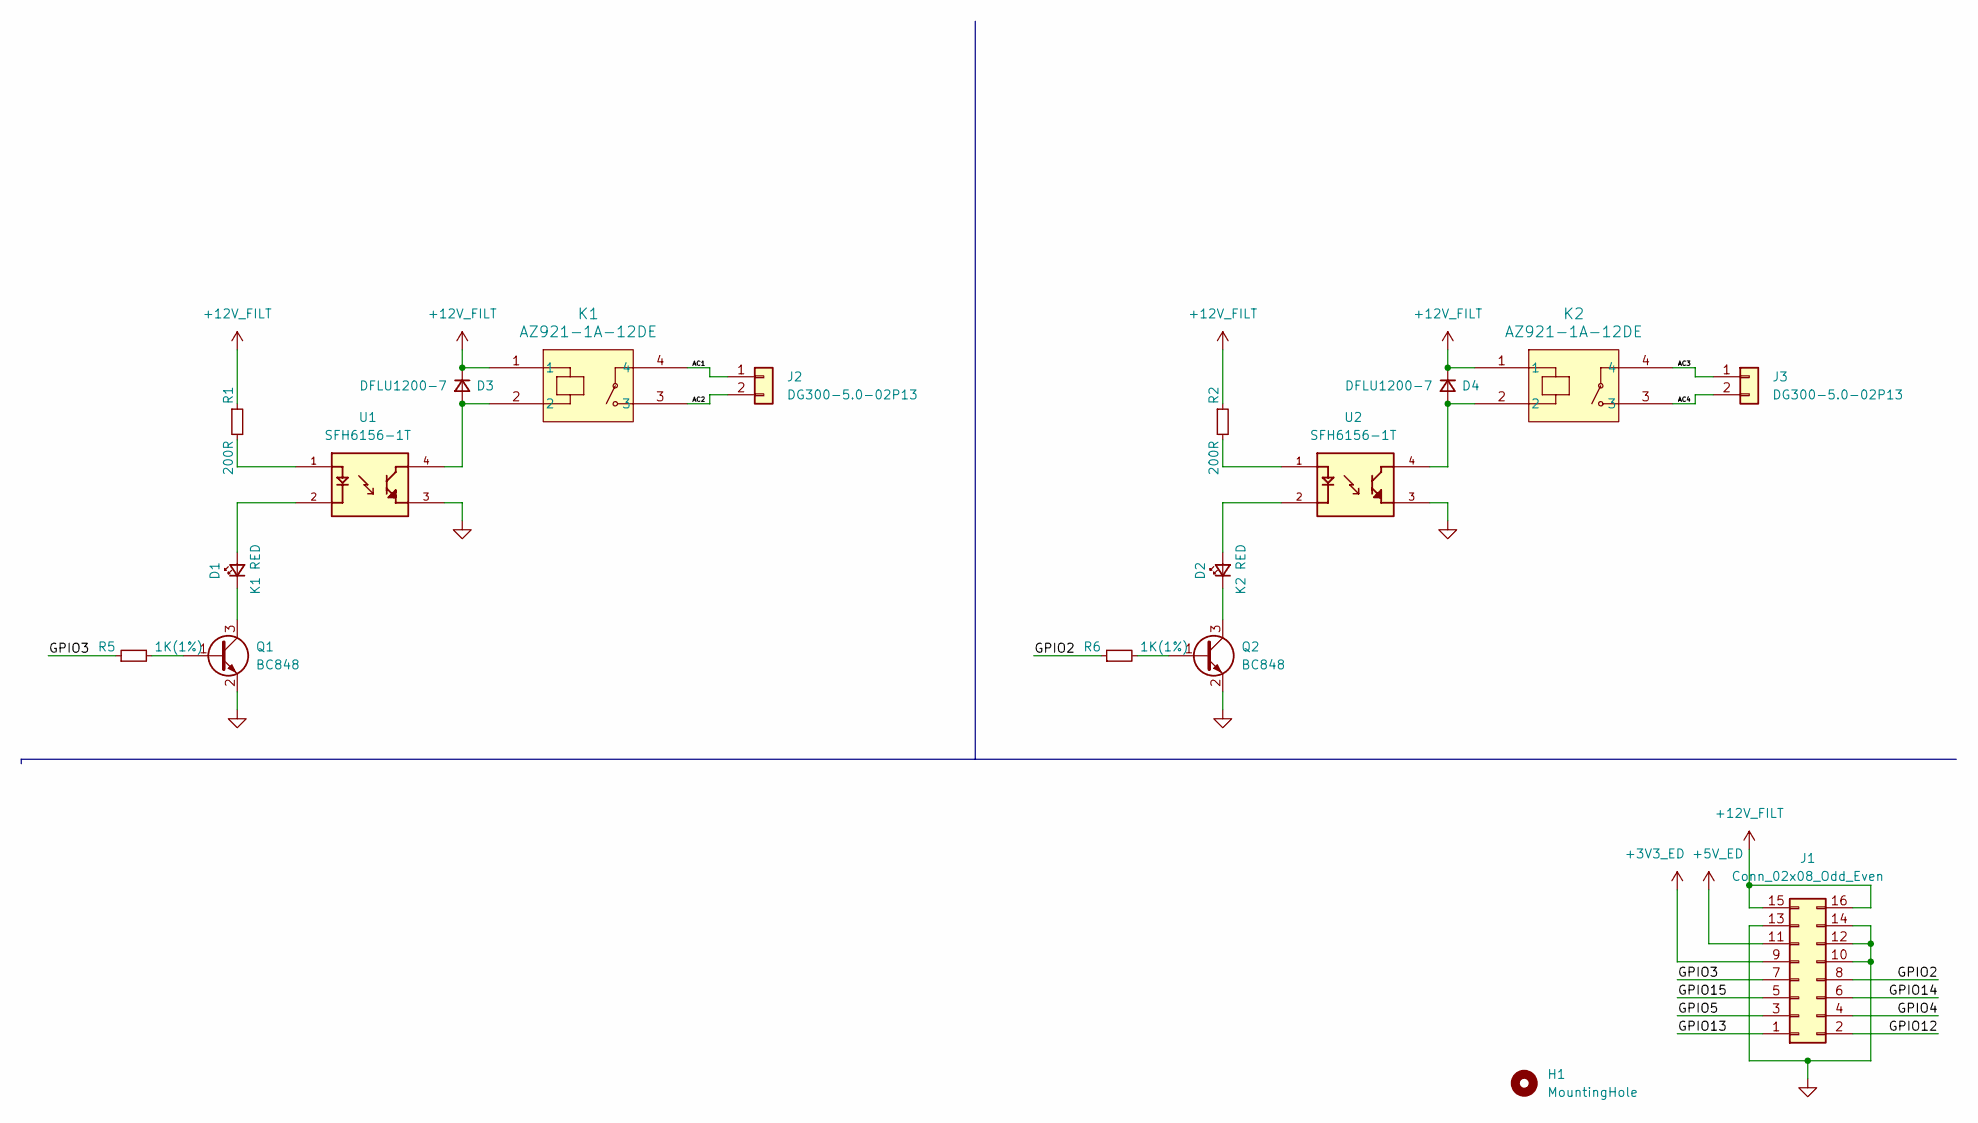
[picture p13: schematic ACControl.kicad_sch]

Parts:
D1: K1 RED; LED_0805_2012Metric
D2: K2 RED; LED_0805_2012Metric
D3, D4: DFLU1200-7; DIODE_DFLU1200_1P93X3_DIO
H1: MountingHole; MountingHole_2.7mm_M2.5
J1: Conn_02x08_Odd_Even; PinHeader_2x08_P2.54mm_Vertical
J2, J3: DG300-5.0-02P13; DG300-5.0-2P
K1, K2: AZ921-1A-12DE; SIP4_AZ921_AMZ
Q1, Q2: BC848; SOT-23
R1, R2: 200R; R_0805_2012Metric
R5, R6: 1K(1%); R_0805_2012Metric
U1, U2: SFH6156-1T; DIGI-KEY_PART_NUMBER 751-1346-1-ND

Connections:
+3V3_ED: J1.9
+5V_ED: J1.11
+12V_FILT: D3.1 (K), D4.1 (K), J1.15, J1.16, K1.1, K2.1, R1.1, R2.1
/AC1: J2.1, K1.4
/AC2: J2.2, K1.3
/AC3: J3.1, K2.4
/AC4: J3.2, K2.3
/GPIO2: J1.8, R6.1
/GPIO3: J1.7, R5.1
/GPIO4: J1.4
/GPIO5: J1.3
/GPIO12: J1.2
/GPIO13: J1.1
/GPIO14: J1.6
/GPIO15: J1.5
GND: J1.10, J1.12, J1.13, J1.14, Q1.2 (E), Q2.2 (E), U1.3, U2.3
unnamed: D1.1 (K), Q1.3 (C)
unnamed: D2.1 (K), Q2.3 (C)
unnamed: Q1.1 (B), R5.2
unnamed: Q2.1 (B), R6.2
unnamed: R1.2, U1.1
unnamed: D1.2 (A), U1.2
unnamed: D3.2 (A), K1.2, U1.4
unnamed: R2.2, U2.1
unnamed: D2.2 (A), U2.2
unnamed: D4.2 (A), K2.2, U2.4

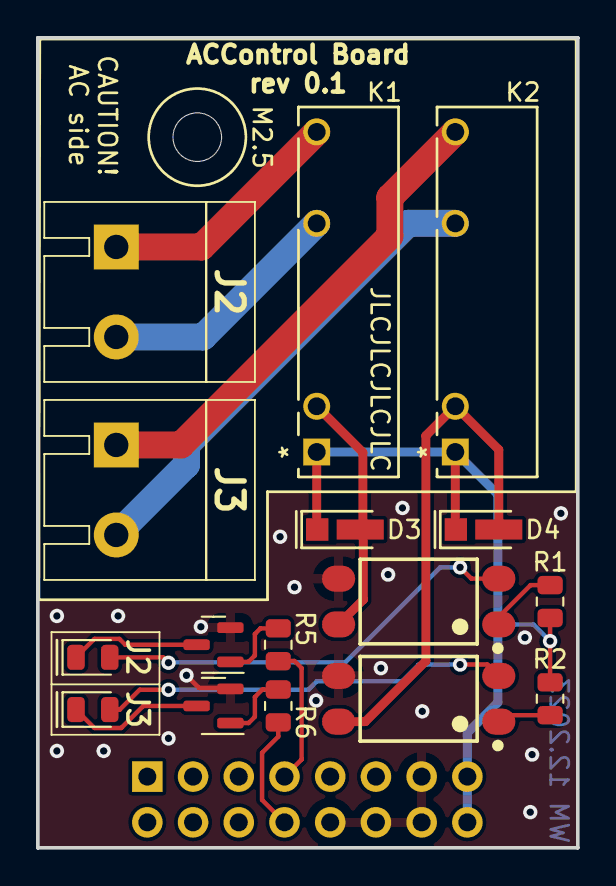
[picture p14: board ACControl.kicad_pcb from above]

Board: 2 copper layers, 30.0 x 45.0 mm, 18 parts (1 on the bottom side), 18 nets.

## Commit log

2024-02-04 Structure changes to schematic files
    [ACControl.kicad_sch, TempSensRTC.kicad_sch]
2024-07-14 revision 0.2
    [HomeAssistant-B_Cu.gbr, HomeAssistant-B_Mask.gbr, HomeAssistant-B_Paste.gbr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]
